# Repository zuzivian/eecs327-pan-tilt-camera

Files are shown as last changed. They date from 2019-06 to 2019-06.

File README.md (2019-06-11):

# FaceAssure
A security camera product that presents that tracks a person's face using openCV in the cloud.

## Description
We are developing a security camera product called FaceAssure that presents the operator a comprehensive view of the area, and a person’s face as it moves across an area, using computer vision and multiple installed cameras. The owner is notified when an unknown person is detected so that they can investigate the situation.

We chose our project because we were interested making it useable for anti-theft purposes at home. Our first idea was to create a network of cameras linked together by a central server that provided an administrative overview for the homeowner. The pan and tilt servos made the most sense in helping a security system cover a large angle in the room. Finally, our interest in exploring computer vision made it possible to control servos autonomous using facial detection.

## More Information
For more description and build instructions, find out more at the Hackaday.io project link
https://hackaday.io/project/166037-faceassure-cloud-based-pan-tilt-security-camera

## Authors
- Nathaniel Wong (@zuzivian)
- Qiankai Cao (@QianKaiCao)

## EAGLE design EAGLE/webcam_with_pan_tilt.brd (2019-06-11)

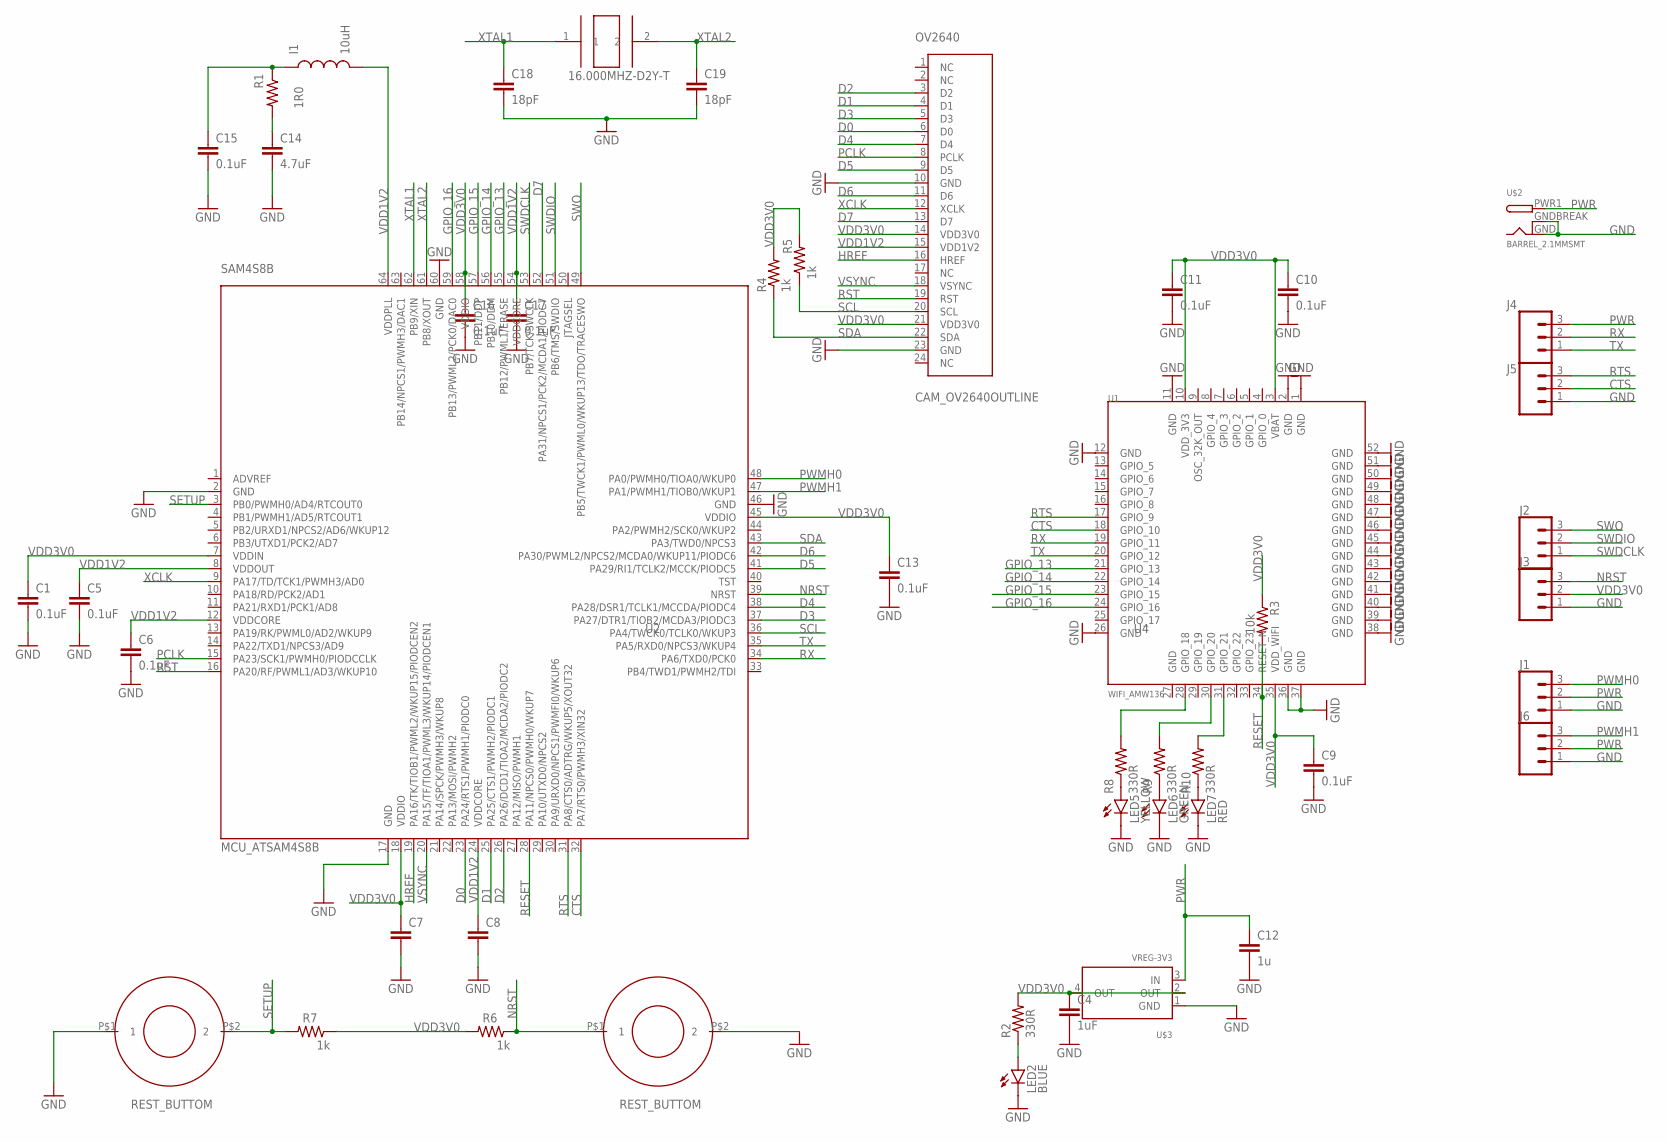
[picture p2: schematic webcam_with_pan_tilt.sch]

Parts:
16.000MHZ-D2Y-T: XTAL_12MHZ; ABM7-16.000MHZ-D2Y-T
C1, C5, C6, C9, C10, C11, C13, C15, C16, C17: 0.1uF; 0805
C4: 1uF; 0805
C7, C8: CAP; 0805
C12: 1u; 0805
C14: 4.7uF; 0805
C18, C19: 18pF; 0805
I1: 10uH; 0805
J1, J2, J3, J4, J5, J6: CONN_03; 1X03
LED2: BLUE; LED-0603
LED5: YELLOW; LED-0603
LED6: GREEN; LED-0603
LED7: RED; LED-0603
OV2640: CAM_OV2640OUTLINE; CAM_CONN
R1: 1R0; 0805
R2, R8, R9, R10: 330R; 0805
R3: 10k; 0805
R4, R5, R6, R7: 1k; 0805
SAM4S8B: MCU_ATSAM4S8B; QFP50P1200X1200X160-64N
U1: WIFI_AMW136; AMW136
U2, U4: REST_BUTTOM; BTN_2
U$2: BARREL_2.1MMSMT; DCJACK_2MM_SMT
U$3: VREG-3V3; R-PDSO-G4_TI

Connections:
CTS: J5.2, SAM4S8B.32 (PA7/RTS0/PWMH3/XIN32), U1.18 (GPIO_10)
D0: OV2640.6 (D0), SAM4S8B.23 (PA24/RTS1/PWMH1/PIODC0)
D1: OV2640.4 (D1), SAM4S8B.25 (PA25/CTS1/PWMH2/PIODC1)
D2: OV2640.3 (D2), SAM4S8B.26 (PA26/DCD1/TIOA2/MCDA2/PIODC2)
D3: OV2640.5 (D3), SAM4S8B.37 (PA27/DTR1/TIOB2/MCDA3/PIODC3)
D4: OV2640.7 (D4), SAM4S8B.38 (PA28/DSR1/TCLK1/MCCDA/PIODC4)
D5: OV2640.9 (D5), SAM4S8B.41 (PA29/RI1/TCLK2/MCCK/PIODC5)
D6: OV2640.11 (D6), SAM4S8B.42 (PA30/PWML2/NPCS2/MCDA0/WKUP11/PIODC6)
D7: OV2640.13 (D7), SAM4S8B.52 (PA31/NPCS1/PCK2/MCDA1/PIODC7)
GND: C1.2, C4.2, C5.2, C6.2, C7.2, C8.2, C9.2, C10.2, C11.2, C12.2, C13.2, C14.2, C15.2, C16.2, C17.2, C18.2, C19.2, J1.1, J3.1, J5.1, J6.1, LED2.C, LED5.C, LED6.C, LED7.C, OV2640.10 (GND), OV2640.23 (GND), SAM4S8B.2 (GND), SAM4S8B.17 (GND), SAM4S8B.46 (GND), SAM4S8B.60 (GND), U1.1 (GND), U1.2 (GND), U1.11 (GND), U1.12 (GND), U1.26 (GND), U1.36 (GND), U1.37 (GND), U1.38 (GND), U1.39 (GND), U1.40 (GND), U1.41 (GND), U1.42 (GND), U1.43 (GND), U1.44 (GND), U1.45 (GND), U1.46 (GND), U1.47 (GND), U1.48 (GND), U1.49 (GND), U1.50 (GND), U1.51 (GND), U1.52 (GND), U2.P$1 (1), U4.P$2 (2), U$2.GND, U$2.GNDBREAK, U$3.1 (GND)
GPIO_13: SAM4S8B.55 (PB12/PWML1/ERASE), U1.21 (GPIO_13)
GPIO_14: SAM4S8B.56 (PB10/DDM), U1.22 (GPIO_14)
GPIO_15: SAM4S8B.57 (PB11/DDP), U1.23 (GPIO_15)
GPIO_16: SAM4S8B.59 (PB13/PWML2/PCK0/DAC0), U1.24 (GPIO_16)
HREF: OV2640.16 (HREF), SAM4S8B.19 (PA16/TK/TIOB1/PWML2/WKUP15/PIODCEN2)
unnamed: C14.1, R1.2
unnamed: C15.1, I1.1, R1.1
unnamed: LED5.A, R8.1
unnamed: LED6.A, R9.1
unnamed: R8.2, U1.28 (GPIO_18)
unnamed: LED2.A, R2.1
unnamed: LED7.A, R10.1
unnamed: R9.2, U1.30 (GPIO_20)
unnamed: R10.2, U1.31 (GPIO_21)
NRST: J3.3, R6.1, SAM4S8B.39 (NRST), U4.P$1 (1)
PCLK: OV2640.8 (PCLK), SAM4S8B.15 (PA23/SCK1/PWMH0/PIODCCLK)
PWMH0: J1.3, SAM4S8B.48 (PA0/PWMH0/TIOA0/WKUP0)
PWMH1: J6.3, SAM4S8B.47 (PA1/PWMH1/TIOB0/WKUP1)
PWR: C12.1, J1.2, J4.3, J6.2, U$2.PWR1 (PWR), U$3.3 (IN)
RESET: R3.2, SAM4S8B.28 (PA11/NPCS0/PWMH0/WKUP7), U1.34 (RESET_N)
RST: OV2640.19 (RST), SAM4S8B.16 (PA20/RF/PWML1/AD3/WKUP10)
RTS: J5.3, SAM4S8B.31 (PA8/CTS0/ADTRG/WKUP5/XOUT32), U1.17 (GPIO_9)
RX: J4.2, SAM4S8B.34 (PA6/TXD0/PCK0), U1.19 (GPIO_11)
SCL: OV2640.20 (SCL), R5.1, SAM4S8B.36 (PA4/TWCK0/TCLK0/WKUP3)
SDA: OV2640.22 (SDA), R4.1, SAM4S8B.43 (PA3/TWD0/NPCS3)
SETUP: R7.2, SAM4S8B.3 (PB0/PWMH0/AD4/RTCOUT0), U2.P$2 (2)
SWDCLK: J2.1, SAM4S8B.53 (PB7/TCK/SWCLK)
SWDIO: J2.2, SAM4S8B.51 (PB6/TMS/SWDIO)
SWO: J2.3, SAM4S8B.49 (PB5/TWCK1/PWML0/WKUP13/TDO/TRACESWO)
TX: J4.1, SAM4S8B.35 (PA5/RXD0/NPCS3/WKUP4), U1.20 (GPIO_12)
VDD1V2: C5.1, C6.1, C8.1, C17.1, I1.2, OV2640.15 (VDD1V2), SAM4S8B.8 (VDDOUT), SAM4S8B.12 (VDDCORE), SAM4S8B.24 (VDDCORE), SAM4S8B.54 (VDDCORE), SAM4S8B.64 (VDDPLL)
VDD3V0: C1.1, C4.1, C7.1, C9.1, C10.1, C11.1, C13.1, C16.1, J3.2, OV2640.14 (VDD3V0), OV2640.21 (VDD3V0), R2.2, R3.1, R4.2, R5.2, R6.2, R7.1, SAM4S8B.7 (VDDIN), SAM4S8B.18 (VDDIO), SAM4S8B.45 (VDDIO), SAM4S8B.58 (VDDIO), U1.3 (VBAT), U1.10 (VDD_3V3), U1.35 (VDD_WIFI), U$3.2 (OUT), U$3.4 (OUT)
VSYNC: OV2640.18 (VSYNC), SAM4S8B.20 (PA15/TF/TIOA1/PWML3/WKUP14/PIODCEN1)
XCLK: OV2640.12 (XCLK), SAM4S8B.9 (PA17/TD/TCK1/PWMH3/AD0)
XTAL1: 16.000MHZ-D2Y-T.1, C18.1, SAM4S8B.62 (PB9/XIN)
XTAL2: 16.000MHZ-D2Y-T.2, C19.1, SAM4S8B.61 (PB8/XOUT)

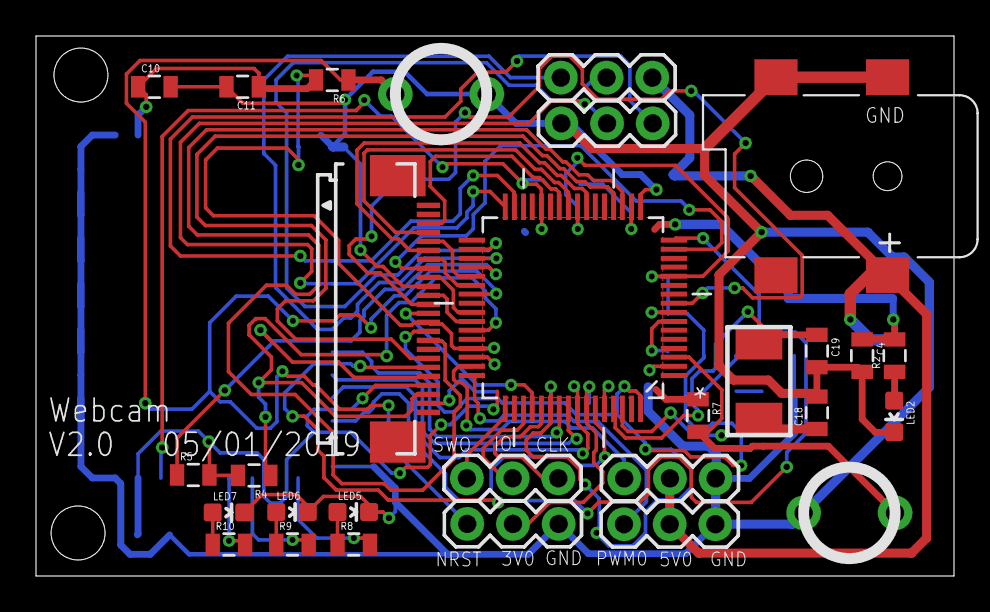
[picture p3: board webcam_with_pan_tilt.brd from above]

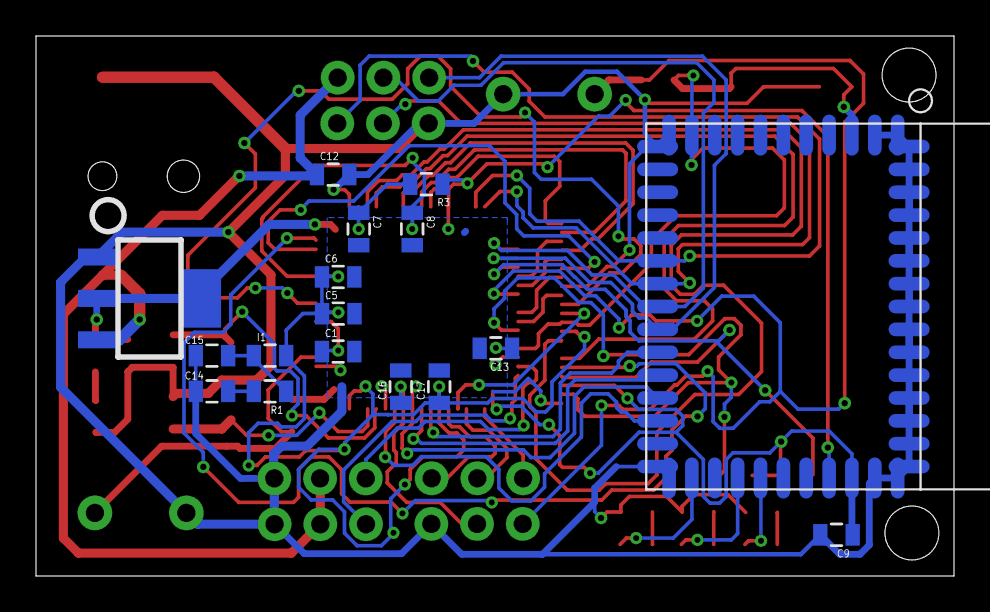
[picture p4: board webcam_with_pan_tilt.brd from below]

Board: 2 copper layers, 51.0 x 30.0 mm, 46 parts (17 on the bottom side), 46 nets.

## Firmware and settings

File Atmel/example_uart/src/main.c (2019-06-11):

#include <asf.h>
#include "conf_board.h"
#include "conf_clock.h"
#include "wifi.h"
#include "camera.h"
#include "servo.h"
#include "timer_interface.h"


int main (void)
{
	sysclk_init();
	wdt_disable(WDT);
	board_init();
	configure_tc();
	
	gpio_set_pin_low(WIFI_RESET_PIN);
	delay_ms(100);
	gpio_set_pin_high(WIFI_RESET_PIN);
	delay_ms(10000);
	
 	configure_usart_wifi();
	configure_wifi_comm_pin();
	configure_wifi_web_setup_pin();
	
	servo_init();
	
	while (ioport_get_pin_level(WIFI_SET)==0) {
		if (setup_web) {
		
		usart_write_line(WIFI_USART, "setup web\r\n");
		setup_web=false;
		}
	}
	
	capture_init();
	g_ul_vsync_flag = false;
	
	while(1) {
		servo_set(&pwm_channel_cam_0, pan_angle);
		servo_set(&pwm_channel_cam_1, tilt_angle);
		
		if (setup_web){
			usart_write_line(WIFI_USART, "setup web\r\n");
			setup_web=false;  
		}
		
		 else if (ioport_get_pin_level(WIFI_SET)==1){
			usart_write_line(WIFI_USART, "poll all\r\n");
				
			if(!web_connected){
				usart_write_line(WIFI_USART, "get wl n s\r\n");
				delay_ms(1000);
			}
			else if (wifi_stream<2) {
				if (wifi_stream ==0) {
					char comm[1000];
					sprintf(comm, "tcpc 35.208.31.153 80\r\n");
					write_wifi_command(comm, 2);
					wifi_stream = 1;
				}
				delay_ms(1000);
			}
			else{
				start_capture();
				write_image_to_file();
			}
		}
	
		else{
			gpio_set_pin_low(WIFI_RESET_PIN);
			delay_ms(50);
			gpio_set_pin_high(WIFI_RESET_PIN);
		}
		
	}
}
			

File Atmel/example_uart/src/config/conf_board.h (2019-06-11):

/**
 * \file
 *
 * \brief Board configuration.
 *
 * Copyright (c) 2012-2015 Atmel Corporation. All rights reserved.
 *
 * \asf_license_start
 *
 * \page License
 *
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
 * 3. The name of Atmel may not be used to endorse or promote products derived
 *    from this software without specific prior written permission.
 *
 * 4. This software may only be redistributed and used in connection with an
 *    Atmel microcontroller product.
 *
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
 * \asf_license_stop
 *
 */
/*
 * Support and FAQ: visit <a href="http://www.atmel.com/design-support/">Atmel Support</a>
 */

#ifndef CONF_BOARD_H_INCLUDED
#define CONF_BOARD_H_INCLUDED

#define IOPROT_CREATE_PIN_0 PIO_PA0_IDX
#define IOPROT_CREATE_PIN_1 PIO_PA1_IDX

#define WIFI_CTS_PIN		PIO_PA7_IDX
#define WIFI_RESET_PIN      PIO_PA11_IDX
#define WIFI_STATUS_PIN		PIO_PB10_IDX
#define WIFI_SET	PIO_PB0_IDX
#define WIFI_COMM			PIO_PB11_IDX
#define CAM_RESET_PIN			PIO_PA20_IDX
// /** Enable OV7740 image sensor. */
// #define CONF_BOARD_OV2640_IMAGE_SENSOR
// 
// /** Configure TWI0 pins (for OV7740  communications). */
// #define CONF_BOARD_TWI0
// 
// /** Configure PCK0 pins (for OV7740  communications). */
// #define CONF_BOARD_PCK0

/* Enable SRAM. */

// Image sensor Power pin.
//#define OV_POWER_PIO                   OV_SW_OVT_PIO
//#define OV_POWER_MASK                  OV_SW_OVT_MASK
// Image sensor VSYNC pin.
#define OV2640_VSYNC_PIO	       OV_VSYNC_PIO
#define OV2640_VSYNC_ID		       OV_VSYNC_ID
#define OV2640_VSYNC_MASK              OV_VSYNC_MASK
#define OV2640_VSYNC_TYPE              OV_VSYNC_TYPE
// Image sensor data pin.
#define OV2640_DATA_BUS_PIO            OV_DATA_BUS_PIO
#define OV2640_DATA_BUS_ID             OV_DATA_BUS_ID

/** Enable Com Port. */
#define CONF_BOARD_UART_CONSOLE

/* TWI board defines. */
#define ID_BOARD_TWI                   ID_TWI0
#define BOARD_TWI                      TWI0
#define BOARD_TWI_IRQn                 TWI0_IRQn

#define BOARD_FREQ_SLCK_XTAL      (32768U)
#define BOARD_FREQ_SLCK_BYPASS    (32768U)
#define BOARD_FREQ_MAINCK_XTAL    (12000000U)
#define BOARD_FREQ_MAINCK_BYPASS  (12000000U)
#define BOARD_MCK                 CHIP_FREQ_CPU_MAX
#define BOARD_OSC_STARTUP_US      15625

//! [tc_define_peripheral]
/* Use TC Peripheral 0. */
#define TC             TC0
#define TC_PERIPHERAL  0
//! [tc_define_peripheral]

//! [tc_define_ch1]
/* Configure TC0 channel 1 as waveform output. */
#define TC_CHANNEL_WAVEFORM 1
#define ID_TC_WAVEFORM      ID_TC1


//! [tc_define_ch2]
/* Configure TC0 channel 2 as capture input. */
#define TC_CHANNEL_CAPTURE 2
#define ID_TC_CAPTURE ID_TC2

//! [tc_define_ch2]

//! [tc_define_irq_handler]
/* Use TC2_Handler for TC capture interrupt. */
#define TC_Handler  TC2_Handler
#define TC_IRQn     TC2_IRQn
//! [tc_define_irq_handler]

#endif /* CONF_BOARD_H_INCLUDED */

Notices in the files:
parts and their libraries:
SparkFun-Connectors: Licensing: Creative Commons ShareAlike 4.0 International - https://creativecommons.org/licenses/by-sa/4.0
